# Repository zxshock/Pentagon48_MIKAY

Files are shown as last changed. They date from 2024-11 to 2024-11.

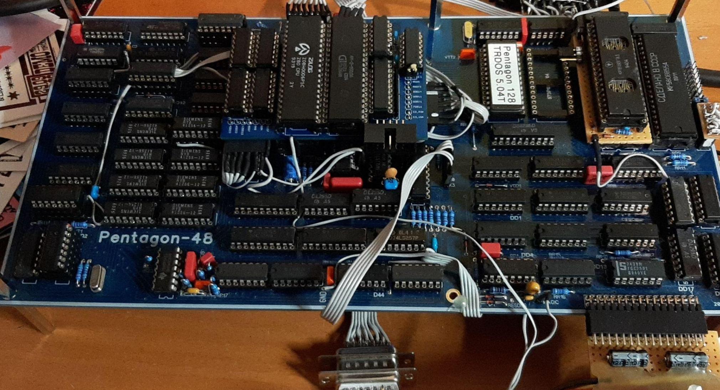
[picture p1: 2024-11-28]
p48_prev.jpg

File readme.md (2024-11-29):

Daughterboard to add support for 128K RAM, adjust INT and timing. Additionally add support for AY-3-8910.
Also features a circuit to add support for Kempston Joystick on Port #31 which is redundant and should *NOT* be populated. Kept for historical purposes or rather because I don't want to redo the layout, which is why I'm including Eagle .sch and .brd files.
Documentation needs some touch-ups to be more clear what to lift/cut and when to attach signals.
Prototyped in 2019

Largely inspired by https://www.youtube.com/watch?v=I8NjLR6Kafg with help from people over at zx-pk.ru

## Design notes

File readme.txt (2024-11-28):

128MIKAY expansion for Pentagon 48

Layout by shock__,
Schematic by various authors (see schematic for full credits)
Version: 0.99 (tested on breadboard)

Contact: [redacted] or "Shockwav3" on the zx-pk.ru Forum
If you find any errors or want to suggest an improvement feel free to contact me.

License: CC-BY-SA-NC
Which means: 
- Don't remove the original credits.
- If you improve this layout/schematic you have to include the original files
- Non commercial. You're free to produce PCBs for yourself and others at a _fair_ price.

Short description: 
This interface allows you to add compatibility to Pentagon 128 programs on Pentagon 48 computers. For the memory
expansion exchange the DRAMs on board with 256K*1 DRAMs and follow the instructions in the .pdf. Modifications to
the mainboard of the computer are described in the .pdf
The value of C1 changes dependant on the type of logic IC used (74/74LS/74ALS/155/555/1533)
If you don't need the Kempston interface (it's redundant if the 8255 is used) you can leave out IC11, RN1, JP1.
MIKAY stands for "Mem - INT - Kempston - AY"

Enjoy!
shock__ - 03/02/2019

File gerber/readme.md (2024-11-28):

Gerber files, still using the Eagle naming scheme
Files are named like a 4 layer board, but only use 2.

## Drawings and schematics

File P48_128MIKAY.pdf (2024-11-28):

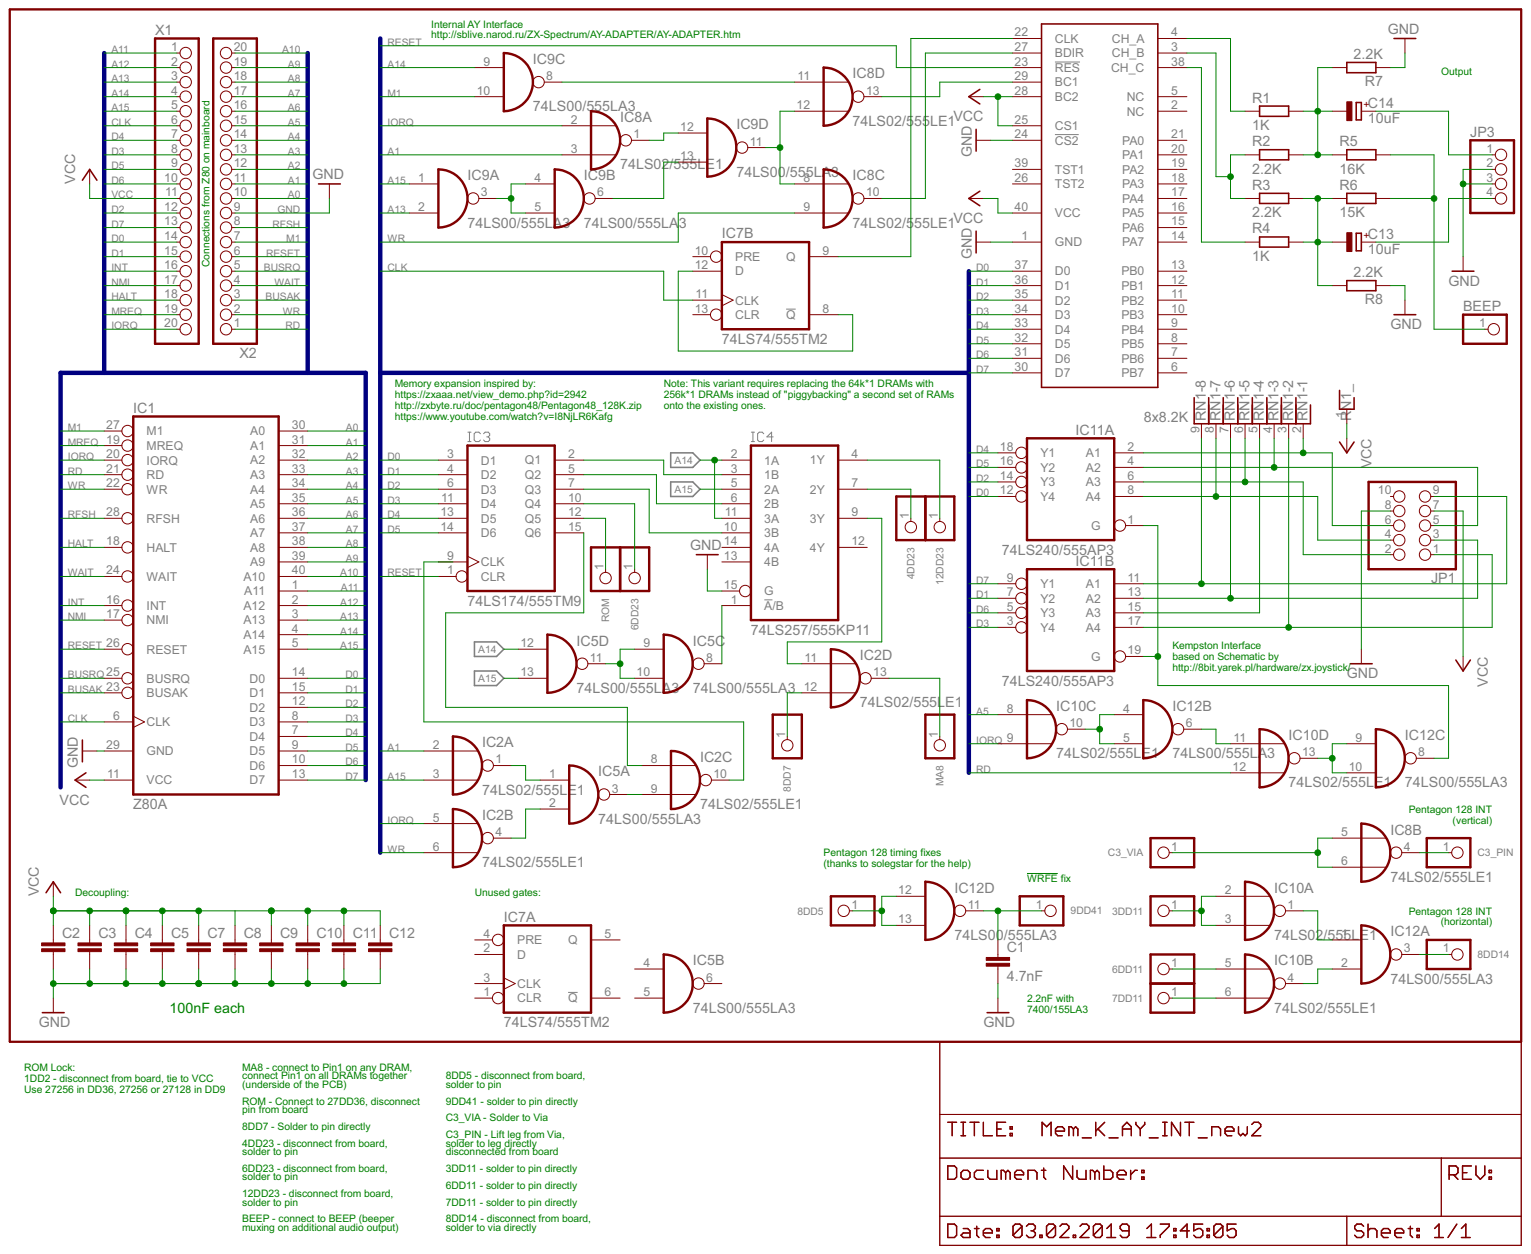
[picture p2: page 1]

Internal AY Interface
http://sblive.narod.ru/ZX-Spectrum/AY-ADAPTER/AY-ADAPTER.htm

+ Connections from Z80 on mainboard

Memory expansion inspired by: https://zxaaa.net/view_demo.php?id=2942

Note: This variant requires replacing the 64k*1 DRAMs with
256k*1 DRAMs instead of "piggybacking" a second set of RAMs onto the existing ones.

http://zxbyte.ru/doc/pentagon48/Pentagon48_128K.zip
https://www.youtube.com/watch?v=I8NjLR6Kafg

Kempston Interface
based on Schematic by http://8bit.yarek.pl/hardware/zx.joystick/

Pentagon 128 timing fixes
(thanks to solegstar for the help)

ROM Lock: 1DD2 - disconnect from board, tie to VCC

MA8 - connect to Pin1 on any DRAM, connect Pin1 on all DRAMs together
(underside of the PCB) ROM - Connect to 27DD36, disconnect pin from board

Use 27256 in DD36, 27256 or 27128 in DD9

8DD5 - disconnect from board, solder to pin

9DD41 - solder to pin directly C3_VIA - Solder to Via C3_PIN - Lift leg from Via, solder to leg directly disconnected from board

8DD7 - Solder to pin directly 4DD23 - disconnect from board, solder to pin

6DD23 - disconnect from board, solder to pin

3DD11 - solder to pin directly 6DD11 - solder to pin directly 7DD11 - solder to pin directly 8DD14 - disconnect from board, solder to via directly

12DD23 - disconnect from board, solder to pin BEEP - connect to BEEP (beeper muxing on additional audio output)
